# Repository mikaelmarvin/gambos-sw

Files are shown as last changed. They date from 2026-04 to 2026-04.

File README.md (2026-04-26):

# gambos

Monorepo for the Gambos project: **hardware** (schematics, PCBs, mechanical) and **software** (STM32 firmware).

| Directory | Contents |
|---|---|
| [`hardware/`](hardware/) | Hardware design files (add your KiCad, STEP, etc. here). |
| [`software/`](software/) | Firmware, CMake project, and [software/README.md](software/README.md) for build and dev container setup. |

Development (Docker, ST-Link, build scripts) is unchanged in spirit; commands now live under `software/project/`. See **software/README.md** for prerequisites, `./software/project/scripts/build.sh`, and the Dev Container workflow.

The dev container `workspaceFolder` is name-agnostic (`/workspace/project/${localWorkspaceFolderBasename}`), so repository renames do not require manual edits.

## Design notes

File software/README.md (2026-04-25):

# Gambos firmware

STM32 firmware for the Gambos project — built with CMake, developed in a **Dev Container** (Docker) at the **repository root** (see the top-level `README.md`).

## Prerequisites

| Requirement | Notes |
|---|---|
| **Git** | Clone this repository. |
| **Docker** + **Docker Compose** | Used by the dev container. |
| **Cursor** or **VS Code** | With the **Dev Containers** extension (`ms-vscode-remote.remote-containers`). |
| **Host OS** | **Linux** recommended for **USB** (ST-Link, serial) into the container. On macOS/Windows, builds work; USB passthrough needs extra host setup. |

## First-time setup (after clone)

1. **Open the repo in the editor** and choose **“Reopen in Container”** (or **Dev Containers: Reopen in Container**).
2. Wait for the image to build and **post-create** to finish. The container runs `.devcontainer/setup.sh`, which runs **`./software/project/scripts/build.sh devkit`** and fixes `compile_commands.json` paths for clangd.
3. **Open a new terminal** so the shell prompt (Starship) and `PATH` are correct.

If anything fails, run **“Dev Containers: Rebuild Container”** once.

## Build firmware

**Use the build script** (from the **repository root**):

```bash
./software/project/scripts/build.sh              # devkit (default)
./software/project/scripts/build.sh devkit     # same
```

From this directory (`software/`) you can instead run:

```bash
./project/scripts/build.sh
```

Artifacts: `software/project/build/devkit/gambos.elf`.

**ARM GCC** (`arm-none-eabi-gcc`) is installed in the container image.

If you configure manually (equivalent to what `build.sh` does), run from **`software/project/`**:

```bash
cd software/project
cmake --preset devkit
cmake --build build/devkit --parallel
```

### Other scripts (run from repo root)

| Script | Purpose |
|---|---|
| `./software/project/scripts/build.sh [devkit]` | Configure (if needed) + build |
| `./software/project/scripts/clean.sh [devkit]` | CMake `clean` for `build/devkit/` |
| `./software/project/scripts/pristine.sh [devkit\|all]` | Delete `build/devkit/`, or `all` to remove all of `software/project/build/` |
| `./software/project/scripts/probe.sh` | OpenOCD: ST-Link + MCU (STM32F4) |
| `./software/project/scripts/flash.sh` | OpenOCD: program `build/devkit/gambos.elf` (build first) |

## Editor / clangd (IntelliSense)

- `compile_commands.json` is generated under `software/project/build/devkit/` when you configure the devkit preset.
- CMSIS-SVD for register view in Cortex-Debug: **`software/STM32F446.svd`** (referenced from `.vscode/launch.json`).
- **`software/.clangd`** points firmware sources at the devkit compilation database.
- If clangd is stale, run `./software/project/scripts/build.sh` once, then **restart clangd** (command palette: **clangd: Restart language server**).

## ST-Link / USB (Linux host)

The compose file passes **`/dev/bus/usb`** and runs the service **`privileged: true`** so OpenOCD can use the ST-Link from inside the container.

On **Ubuntu**, add your user to **`dialout`** on the host if you use USB serial adapters (log out and back in):

```bash
sudo usermod -aG dialout $USER
```

After changing `docker-compose.yml`, recreate the stack:

```bash
docker compose down && docker compose up -d --build
```

Then **reopen the Dev Container**.

## Flash with OpenOCD (from the container)

After a successful build, from the **repo root**:

```bash
./software/project/scripts/flash.sh
```

Equivalent manual `openocd` lines (paths depend on your workspace location):

**F446 devkit:** `interface/stlink.cfg` + `target/stm32f4x.cfg` + `program …/software/project/build/devkit/gambos.elf verify reset exit`

Probe only: `./software/project/scripts/probe.sh`

## Repo layout (short)

| Path | Purpose |
|---|---|
| `software/project/CMakeLists.txt` | Top-level CMake |
| `software/project/scripts/gen-board-sources.sh` | Generates build inputs from Cube CMake (`build/<preset>/generated/*.cmake`) |
| `software/project/board/devkit/` | Board-specific CubeMX output |
| `software/project/app/devkit/` | Devkit application |
| `.devcontainer/` (repo root) | Dev Container definition and setup script |
| `software/.clangd` | clangd compilation database routing |
| `software/STM32F446.svd` | CMSIS-SVD for STM32F446 (peripherals in the debugger) |

More detail: `software/project/board/README.md`, `software/project/app/README.md`.

## What to commit so the next clone “just works”

Keep these in the repo (already tracked):

- **`.devcontainer/`** — container definition and `setup.sh`
- **`Dockerfile`**, **`docker-compose.yml`** — image and USB settings
- **`software/project/CMakePresets.json`**, **`software/project/CMakeLists.txt`**, **`software/project/scripts/`** — build system
- **`software/.clangd`**, **`software/.clang-format`** — editor / formatter for firmware

Avoid committing **`software/project/build/`** or editor caches — they belong in `.gitignore`.

## Troubleshooting

| Issue | What to try |
|---|---|
| clangd errors in `app/devkit` | `./software/project/scripts/build.sh` (or `cd software/project && cmake --preset devkit`), restart clangd. |
| `compile_commands` paths wrong in container | `docker compose` runs `setup.sh --post-start` to rewrite paths. |
| OpenOCD cannot see ST-Link | Host: `lsusb`; Linux + Docker: recreate container after compose changes; check `privileged` and `/dev/bus/usb` mount. |
| CMake cannot find preset | Prefer `./software/project/scripts/build.sh` from repo root, or run `cmake` from **`software/project/`**. |

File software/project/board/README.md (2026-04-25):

# Board support

## F446 devkit

CubeMX output lives under **`board/devkit/`**: **`Core/`** (or `Inc`/`Src`), **`Drivers/`**, **`Middlewares/`**, `.ioc`, and the **Cube-generated CMake** tree (`CMakeLists.txt`, **`cmake/`**).

### Two CMake entry points (both valid)

| Where you configure | Purpose |
|---|---|
| **`software/project/`** (this repo) | Builds firmware target **`gambos`**. `scripts/gen-board-sources.sh` reads Cube-generated files under `board/devkit/cmake/` and writes generated inputs under `build/devkit/generated/` (`toolchain.cmake`, `cubemx_paths.cmake`). Top `CMakeLists.txt` then consumes those generated files plus `app/${BOARD}/` and `custom_drivers`. |
| **`board/devkit/`** as CMake source root | STM32CubeIDE / Cube “generated project” flow: uses **`board/devkit/CMakeLists.txt`** and **`board/devkit/cmake/`** as shipped by Cube. |

Do not hand-edit Cube’s **`board/devkit/CMakeLists.txt`** or **`board/devkit/cmake/`** for the `gambos` build; they are treated as generated input.

- **startup** — optional in `board/devkit/`; otherwise `software/project/startup_stm32f446xx.s` is used.
- **Linker script** — `board/devkit/STM32F446XX_FLASH.ld` (path is parsed from Cube toolchain and emitted into `build/devkit/generated/toolchain.cmake`).

Build **gambos** from `software/project/`:

```bash
./scripts/build.sh devkit
```

Direct `cmake --preset devkit` works only after generated inputs already exist under `build/devkit/generated/`.

HAL/RTOS source list is parsed from Cube-generated `board/devkit/cmake/stm32cubemx/CMakeLists.txt`.

## Application code

Firmware app code: `app/devkit/` — see `app/README.md`.

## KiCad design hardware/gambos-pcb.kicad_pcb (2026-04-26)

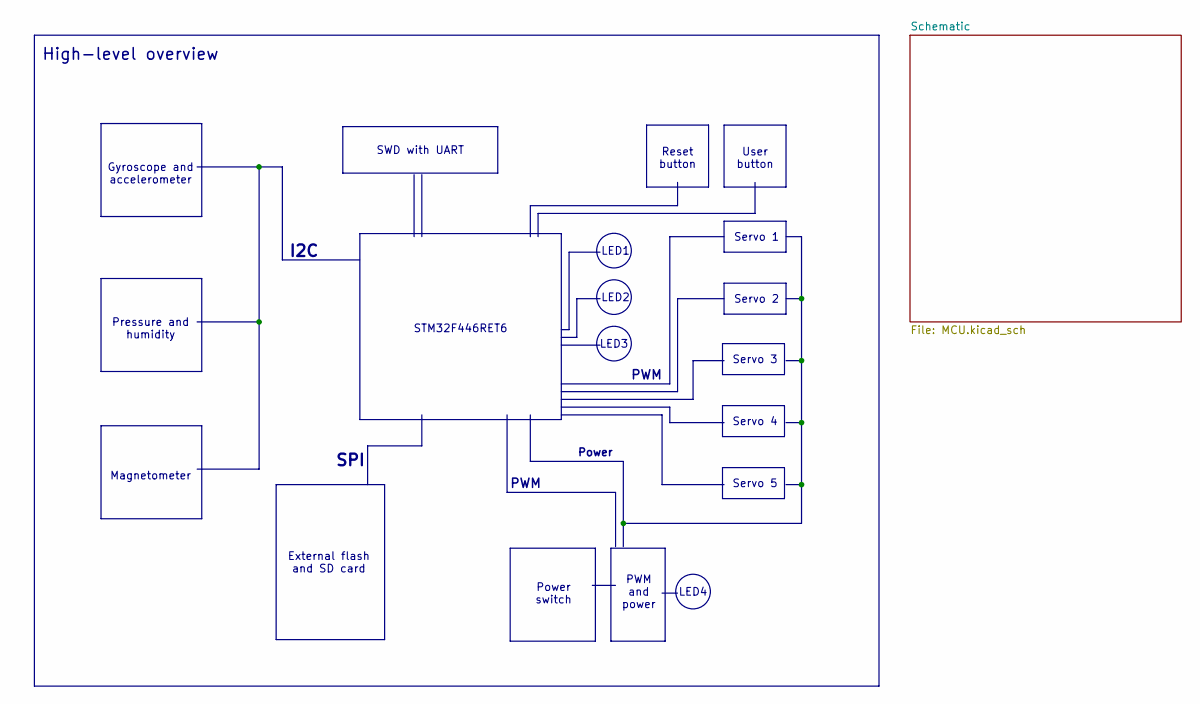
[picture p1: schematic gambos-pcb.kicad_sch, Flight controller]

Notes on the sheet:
I2C
PWM
Servo 4
Magnetometer
Servo 5
External flash and SD card
Servo 3
User button
LED1
LED4
Pressure and humidity
LED3
Power
SPI
Servo 1
High-level overview
Power switch
Reset button
LED2
Gyroscope and accelerometer
PWM and power
SWD with UART
Servo 2
STM32F446RET6

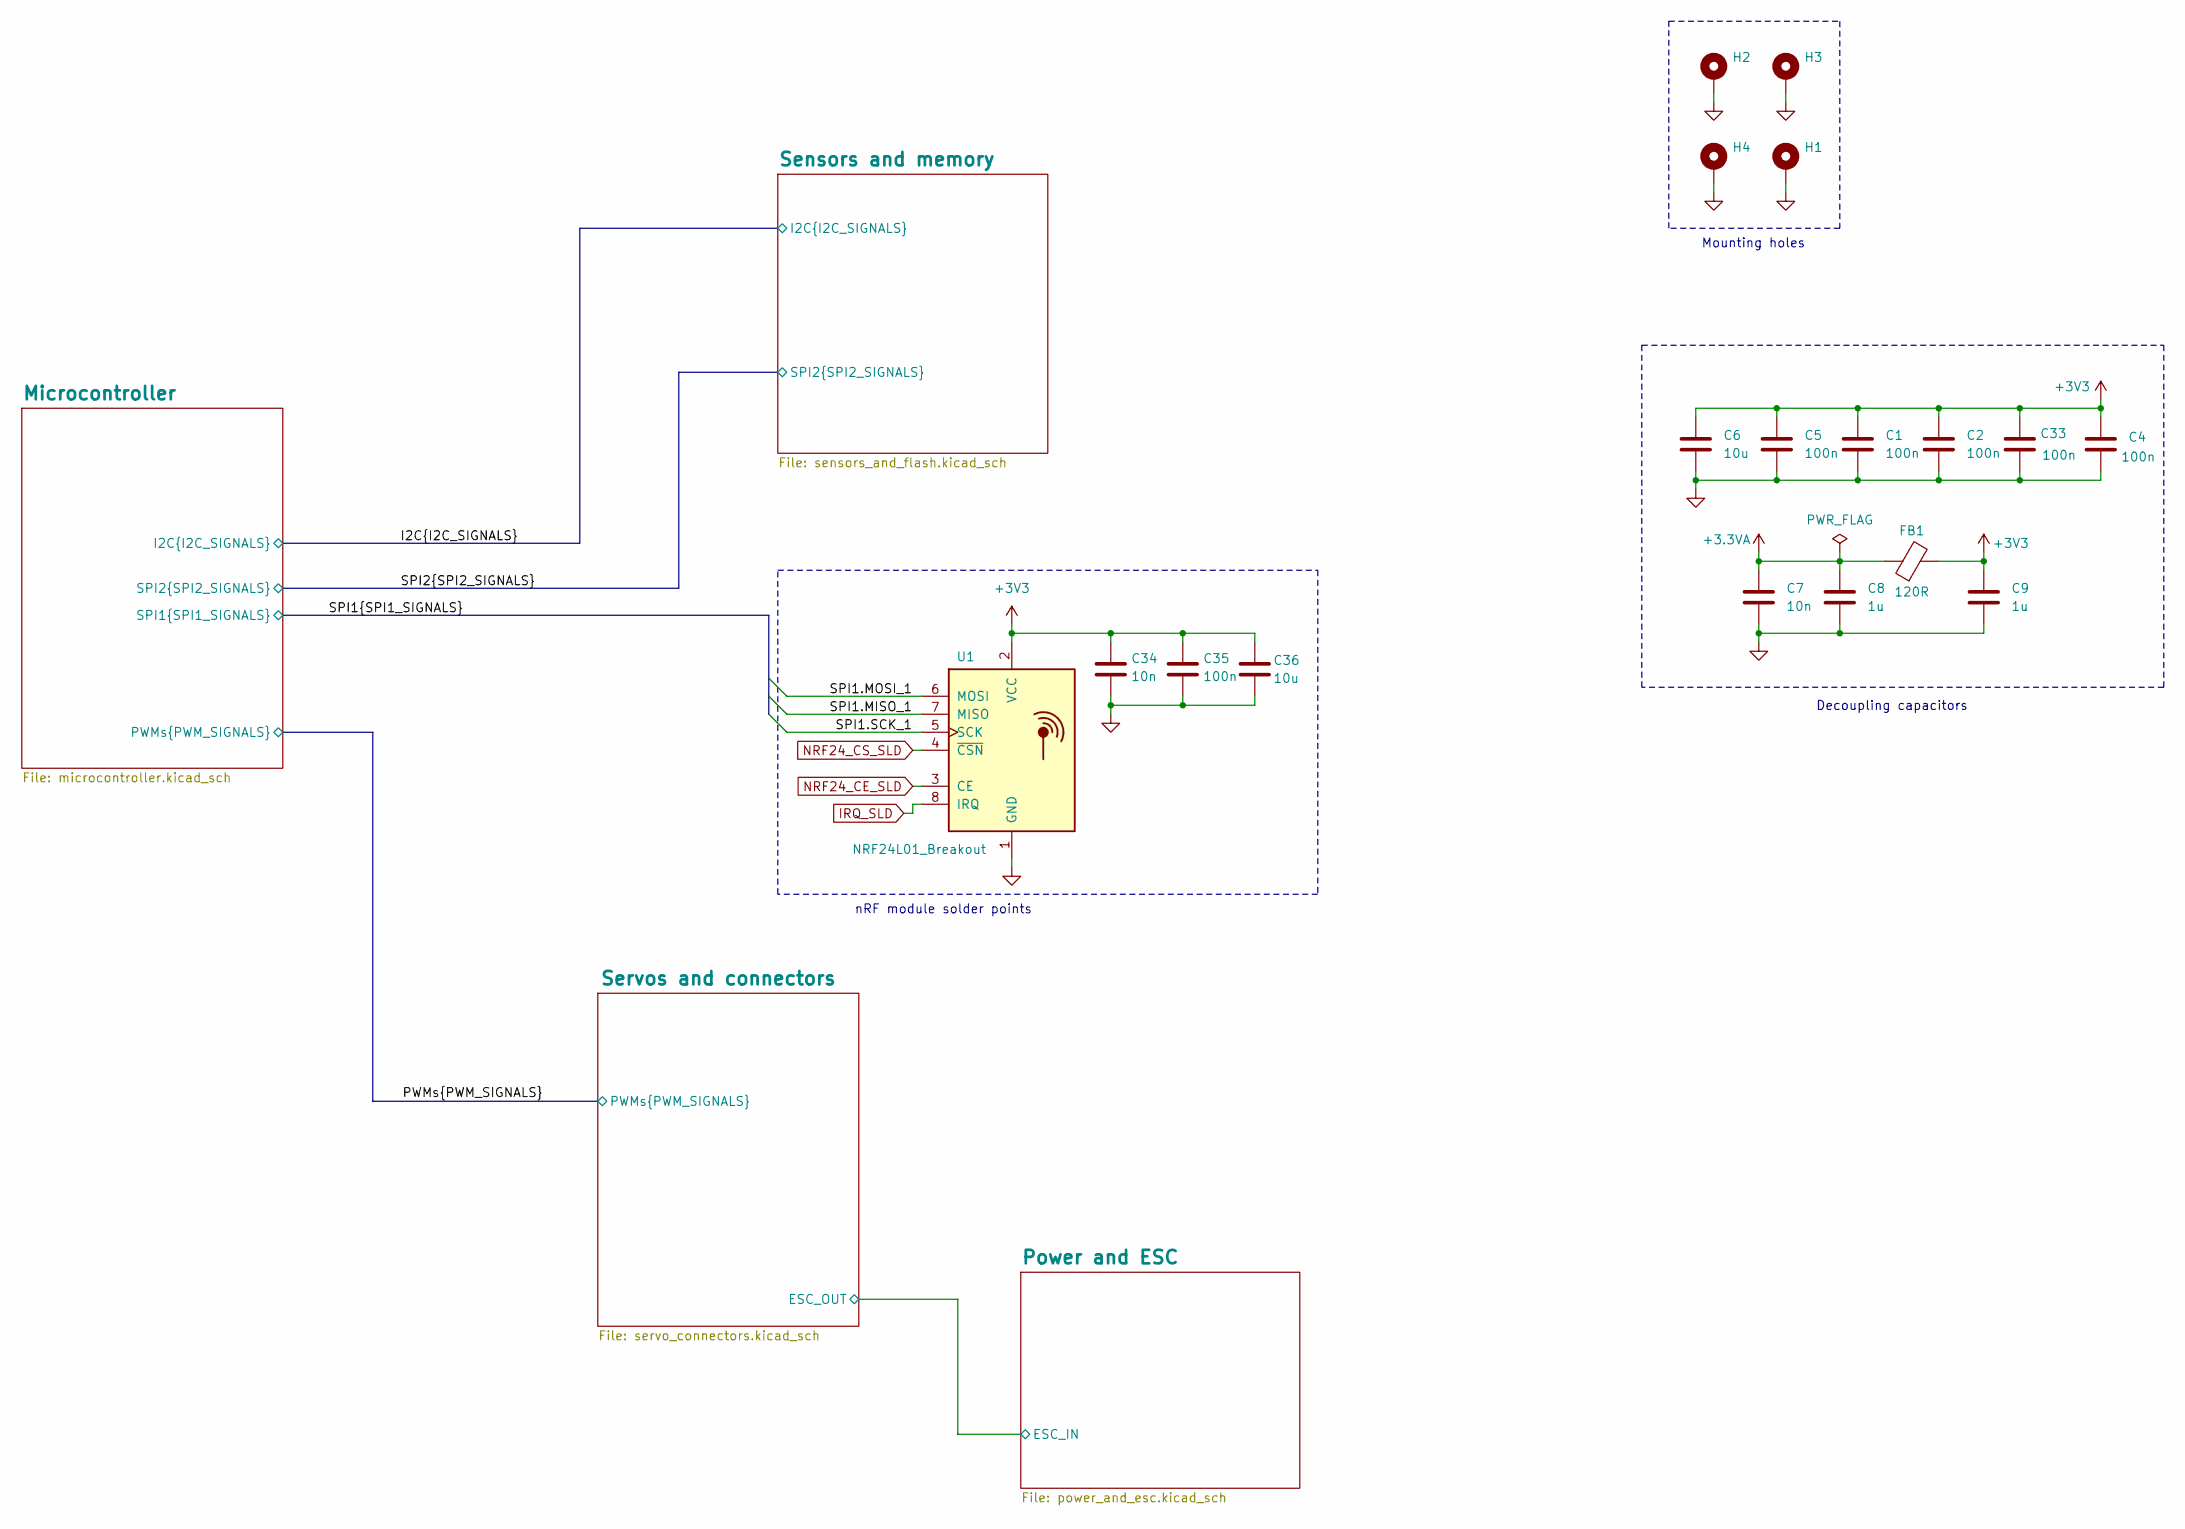
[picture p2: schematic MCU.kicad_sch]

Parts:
C1, C2, C4, C5, C33, C35: 100n; C_0603_1608Metric
C6, C36: 10u; C_0603_1608Metric
C7, C34: 10n; C_0603_1608Metric
C8, C9: 1u; C_0603_1608Metric
FB1: 120R; L_0603_1608Metric
H1, H2, H3, H4: MountingHole_Pad; MountingHole_2.2mm_M2_DIN965_Pad
U1: NRF24L01_Breakout; nRF24L01_Breakout

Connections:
+3.3VA: C7.1, C8.1, FB1.1; also elsewhere on the board
+3V3: C1.1, C2.1, C4.1, C5.1, C6.1, C9.1, C33.1, C34.1, C35.1, C36.1, FB1.2, U1.2 (VCC); also elsewhere on the board
/Schematic/SPI1.MISO_1: U1.7 (MISO); also elsewhere on the board
/Schematic/SPI1.MOSI_1: U1.6 (MOSI); also elsewhere on the board
/Schematic/SPI1.SCK_1: U1.5 (SCK); also elsewhere on the board
GND: C1.2, C2.2, C4.2, C5.2, C6.2, C7.2, C8.2, C9.2, C33.2, C34.2, C35.2, C36.2, H1.1 (1_1), H2.1 (1_1), H3.1 (1_1), H4.1 (1_1), U1.1 (GND); also elsewhere on the board
IRQ_SLD: U1.8 (IRQ); also elsewhere on the board
NRF24_CE_SLD: U1.3 (CE); also elsewhere on the board
NRF24_CS_SLD: U1.4 (~CSN); also elsewhere on the board

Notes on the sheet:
Mounting holes
nRF module solder points
Decoupling capacitors

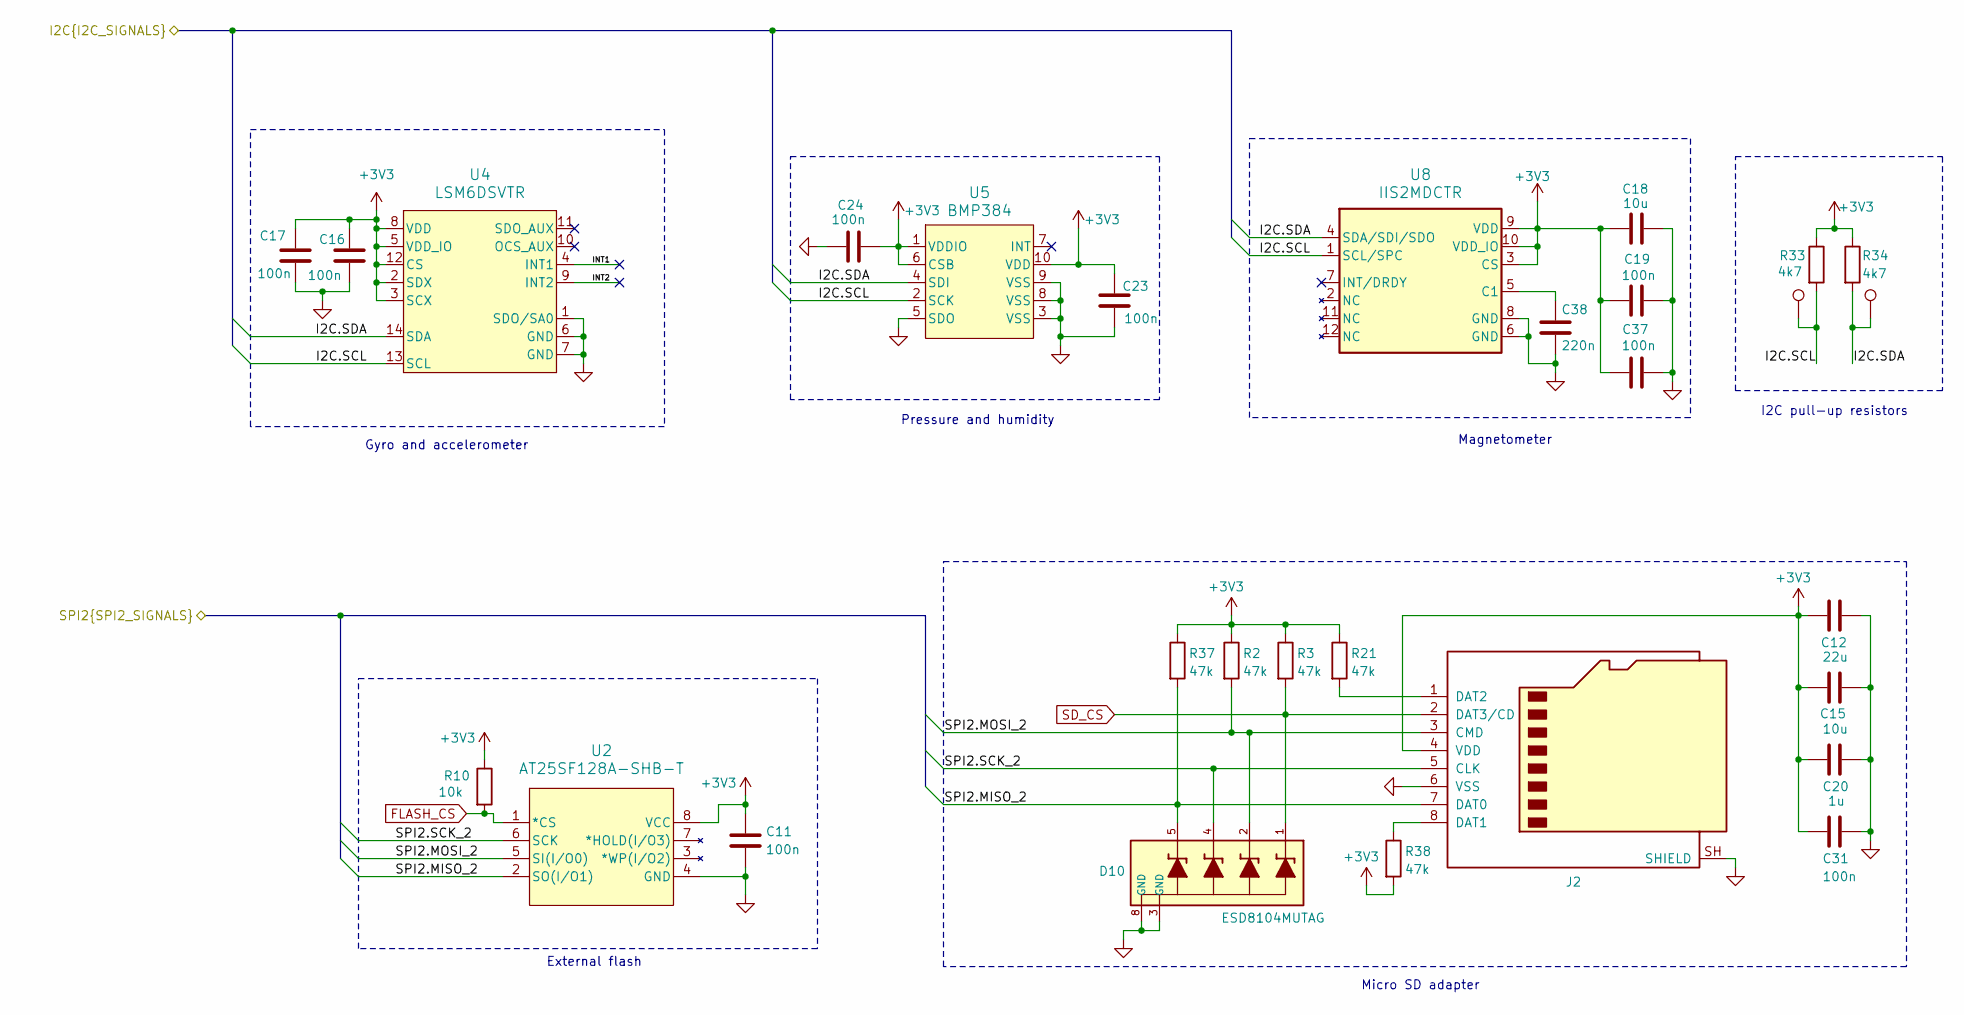
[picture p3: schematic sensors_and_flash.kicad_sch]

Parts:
C11, C16, C17, C19, C23, C24, C31, C37: 100n; C_0603_1608Metric
C12: 22u; C_0603_1608Metric
C15, C18: 10u; C_0603_1608Metric
C20: 1u; C_0603_1608Metric
C38: 220n; C_0603_1608Metric
D10: ESD8104MUTAG; DIO_ESD8104MUTAG
J2: Micro_SD_Card; GCT_MEM2067-02-180-00-A_REVB
R2, R3, R21, R37, R38: 47k; R_0603_1608Metric
R10: 10k; R_0603_1608Metric
R33, R34: 4k7; R_0603_1608Metric
TP12, TP13: TestPoint; TestPoint_Pad_D1.0mm
U2: AT25SF128A-SHB-T; IC8_AT25SF128A-SHB-T_ADO
U4: LSM6DSVTR
U5: BMP384; LGA10_2.0X2.0X0.95_BOS
U8: IIS2MDCTR; LGA-12_2X2X0P7_STM

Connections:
+3V3: C11.1, C12.2, C15.2, C16.1, C17.1, C18.1, C19.1, C20.2, C23.1, C24.2, C31.2, C37.1, J2.4 (VDD), R2.1, R3.1, R10.1, R21.1, R33.1, R34.1, R37.1, R38.2, U2.8 (VCC), U4.2 (SDX), U4.3 (SCX), U4.5 (VDD_IO), U4.8 (VDD), U4.12 (CS), U5.1 (VDDIO), U5.6 (CSB), U5.10 (VDD), U8.3 (CS), U8.9 (VDD), U8.10 (VDD_IO); also elsewhere on the board
/Schematic/I2C.SCL: R33.2, TP12.1 (1_1), U4.13 (SCL), U5.2 (SCK), U8.1 (SCL/SPC); also elsewhere on the board
/Schematic/I2C.SDA: R34.2, TP13.1 (1_1), U4.14 (SDA), U5.4 (SDI), U8.4 (SDA/SDI/SDO); also elsewhere on the board
/Schematic/SPI2.MISO_2: D10.5, J2.7 (DAT0), R37.2, U2.2 (SO(I/O1)); also elsewhere on the board
/Schematic/SPI2.MOSI_2: D10.2, J2.3 (CMD), R2.2, U2.5 (SI(I/O0)); also elsewhere on the board
/Schematic/SPI2.SCK_2: D10.4, J2.5 (CLK), U2.6 (SCK); also elsewhere on the board
/Schematic/Sensors and memory/INT1: U4.4 (INT1)
/Schematic/Sensors and memory/INT2: U4.9 (INT2)
FLASH_CS: R10.2, U2.1 (*CS); also elsewhere on the board
GND: C11.2, C12.1, C15.1, C16.2, C17.2, C18.2, C19.2, C20.1, C23.2, C24.1, C31.1, C37.2, C38.2, D10.3 (GND), D10.8 (GND), J2.6 (VSS), J2.9, J2.10, J2.11, J2.12, J2.SH (SHIELD), U2.4 (GND), U4.1 (SDO/SA0), U4.6 (GND), U4.7 (GND), U5.3 (VSS), U5.5 (SDO), U5.8 (VSS), U5.9 (VSS), U8.6 (GND), U8.8 (GND); also elsewhere on the board
unnamed: J2.8 (DAT1), R38.1
unnamed: J2.1 (DAT2), R21.2
unnamed: C38.1, U8.5 (C1)
SD_CS: D10.1, J2.2 (DAT3/CD), R3.2; also elsewhere on the board

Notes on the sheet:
External flash
Gyro and accelerometer
Pressure and humidity
Magnetometer
Micro SD adapter
I2C pull-up resistors

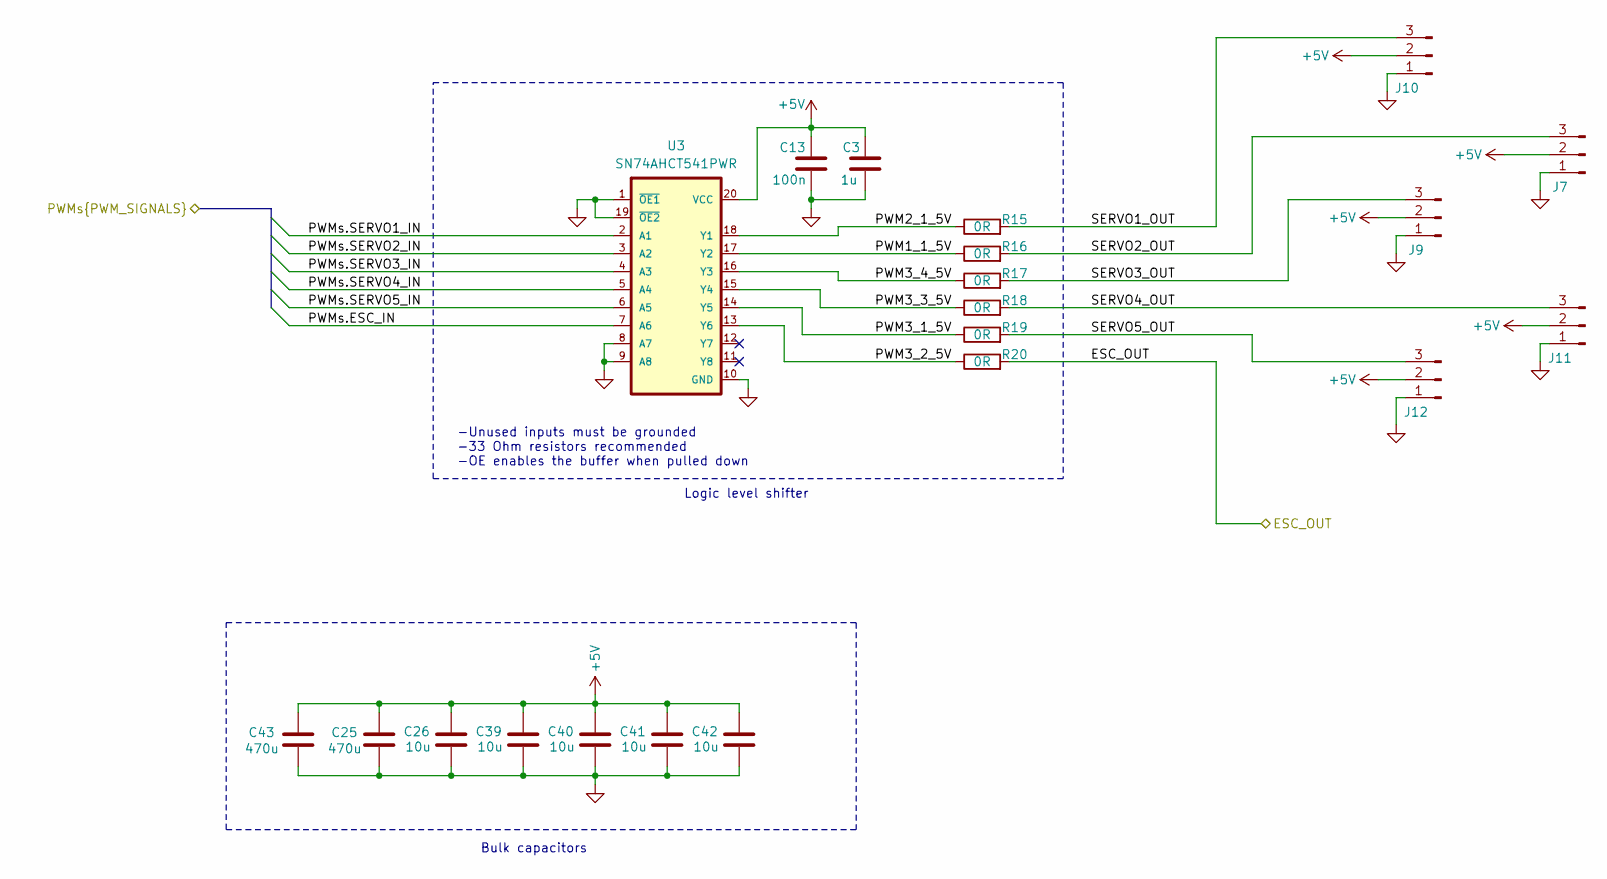
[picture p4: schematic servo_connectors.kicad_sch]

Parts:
C3: 1u; C_0603_1608Metric
C13: 100n; C_0603_1608Metric
C25, C43: 470u; WCAP-ATG8_6.3X11_DXL_
C26, C39, C40, C41, C42: 10u; C_0603_1608Metric
J7, J9, J10, J11, J12: Conn_01x03_Pin; PinHeader_1x03_P2.54mm_Vertical
R15, R16, R17, R18, R19, R20: 0R; R_0603_1608Metric
U3: SN74AHCT541PWR; SOP65P640X120-20N

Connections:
+5V: C3.1, C13.1, C25.1, C26.1, C39.1, C40.1, C41.1, C42.1, C43.1, J7.2, J9.2, J10.2, J11.2, J12.2, U3.20 (VCC); also elsewhere on the board
/Schematic/Microcontroller/PWMs.ESC_IN: U3.7 (A6); also elsewhere on the board
/Schematic/Microcontroller/PWMs.SERVO1_IN: U3.2 (A1); also elsewhere on the board
/Schematic/Microcontroller/PWMs.SERVO2_IN: U3.3 (A2); also elsewhere on the board
/Schematic/Microcontroller/PWMs.SERVO3_IN: U3.4 (A3); also elsewhere on the board
/Schematic/Microcontroller/PWMs.SERVO4_IN: U3.5 (A4); also elsewhere on the board
/Schematic/Microcontroller/PWMs.SERVO5_IN: U3.6 (A5); also elsewhere on the board
/Schematic/Servos and connectors/ESC_OUT: R20.2; also elsewhere on the board
/Schematic/Servos and connectors/PWM1_1_5V: R16.1, U3.17 (Y2)
/Schematic/Servos and connectors/PWM2_1_5V: R15.1, U3.18 (Y1)
/Schematic/Servos and connectors/PWM3_1_5V: R19.1, U3.14 (Y5)
/Schematic/Servos and connectors/PWM3_2_5V: R20.1, U3.13 (Y6)
/Schematic/Servos and connectors/PWM3_3_5V: R18.1, U3.15 (Y4)
/Schematic/Servos and connectors/PWM3_4_5V: R17.1, U3.16 (Y3)
/Schematic/Servos and connectors/SERVO1_OUT: J10.3, R15.2
/Schematic/Servos and connectors/SERVO2_OUT: J7.3, R16.2
/Schematic/Servos and connectors/SERVO3_OUT: J9.3, R17.2
/Schematic/Servos and connectors/SERVO4_OUT: J11.3, R18.2
/Schematic/Servos and connectors/SERVO5_OUT: J12.3, R19.2
GND: C3.2, C13.2, C25.2, C26.2, C39.2, C40.2, C41.2, C42.2, C43.2, J7.1, J9.1, J10.1, J11.1, J12.1, U3.1 (~OE1), U3.8 (A7), U3.9 (A8), U3.10 (GND), U3.19 (~OE2); also elsewhere on the board

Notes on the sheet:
Bulk capacitors
Logic level shifter
-Unused inputs must be grounded -33 Ohm resistors recommended -OE enables the buffer when pulled down

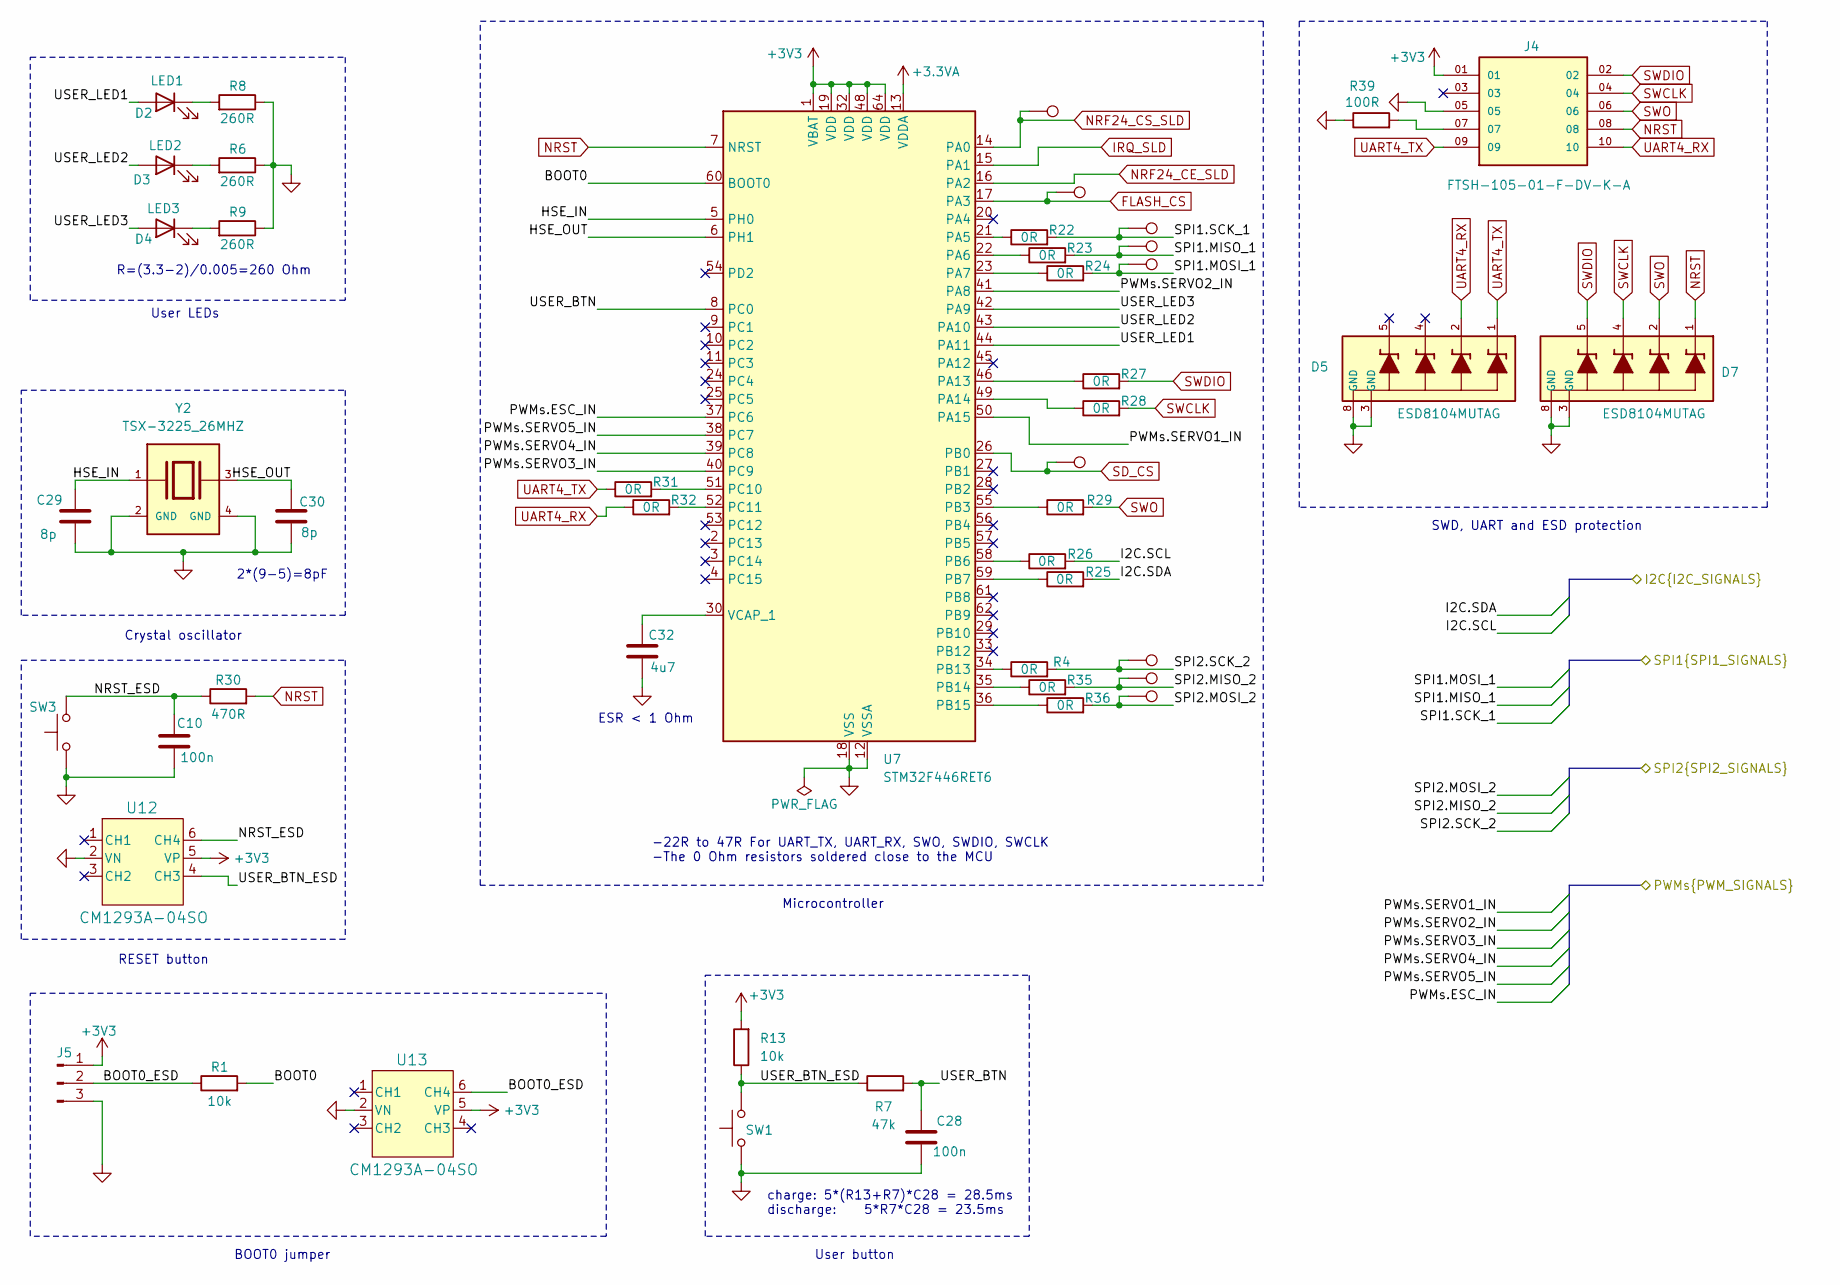
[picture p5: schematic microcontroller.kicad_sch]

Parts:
C10, C28: 100n; C_0603_1608Metric
C29, C30: 8p; C_0603_1608Metric
C32: 4u7; C_0603_1608Metric
D2: LED1; LED_0603_1608Metric
D3: LED2; LED_0603_1608Metric
D4: LED3; LED_0603_1608Metric
D5, D7: ESD8104MUTAG; DIO_ESD8104MUTAG
J4: FTSH-105-01-F-DV-K-A; SAMTEC_FTSH-105-01-F-DV-K-A
J5: Conn_01x03_Pin; PinHeader_1x03_P2.54mm_Vertical
R1, R13: 10k; R_0603_1608Metric
R4, R22, R23, R24, R25, R26, R27, R28, R29, R31, R32, R35, R36: 0R; R_0603_1608Metric
R6, R8, R9: 260R; R_0603_1608Metric
R7: 47k; R_0603_1608Metric
R30: 470R; R_0603_1608Metric
R39: 100R; R_0603_1608Metric
SW1, SW3: SW_Push; SW_Push_1P1T_NO_E-Switch_TL3301NxxxxxG
TP2, TP3, TP4, TP5, TP6, TP7, TP8, TP9, TP14: TestPoint; TestPoint_Pad_D1.0mm
U7: STM32F446RET6
U12, U13: CM1293A-04SO; SC74-6_3P1X1P7_ONS
Y2: TSX-3225_26MHZ; XTAL_TSX-3225_26.0000MF09Z-AC0

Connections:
+3.3VA: U7.13 (VDDA); also elsewhere on the board
+3V3: J4.01, J5.1, R13.2, U7.1 (VBAT), U7.19 (VDD), U7.32 (VDD), U7.48 (VDD), U7.64 (VDD), U12.5 (VP), U13.5 (VP); also elsewhere on the board
/Schematic/I2C.SCL: R26.2; also elsewhere on the board
/Schematic/I2C.SDA: R25.2; also elsewhere on the board
/Schematic/Microcontroller/BOOT0: R1.2, U7.60 (BOOT0)
/Schematic/Microcontroller/BOOT0_ESD: J5.2, R1.1, U13.6 (CH4)
/Schematic/Microcontroller/HSE_IN: C29.2, U7.5 (PH0), Y2.1
/Schematic/Microcontroller/HSE_OUT: C30.1, U7.6 (PH1), Y2.3
/Schematic/Microcontroller/NRST_ESD: C10.1, R30.1, SW3.2, U12.6 (CH4)
/Schematic/Microcontroller/PWMs.ESC_IN: U7.37 (PC6); also elsewhere on the board
/Schematic/Microcontroller/PWMs.SERVO1_IN: U7.50 (PA15); also elsewhere on the board
/Schematic/Microcontroller/PWMs.SERVO2_IN: U7.41 (PA8); also elsewhere on the board
/Schematic/Microcontroller/PWMs.SERVO3_IN: U7.40 (PC9); also elsewhere on the board
/Schematic/Microcontroller/PWMs.SERVO4_IN: U7.39 (PC8); also elsewhere on the board
/Schematic/Microcontroller/PWMs.SERVO5_IN: U7.38 (PC7); also elsewhere on the board
/Schematic/Microcontroller/USER_BTN: C28.1, R7.2, U7.8 (PC0)
/Schematic/Microcontroller/USER_BTN_ESD: R7.1, R13.1, SW1.2, U12.4 (CH3)
/Schematic/Microcontroller/USER_LED1: D2.2 (A), U7.44 (PA11)
/Schematic/Microcontroller/USER_LED2: D3.2 (A), U7.43 (PA10)
/Schematic/Microcontroller/USER_LED3: D4.2 (A), U7.42 (PA9)
/Schematic/SPI1.MISO_1: R23.2, TP4.1 (1_1); also elsewhere on the board
/Schematic/SPI1.MOSI_1: R24.2, TP5.1 (1_1); also elsewhere on the board
/Schematic/SPI1.SCK_1: R22.2, TP3.1 (1_1); also elsewhere on the board
/Schematic/SPI2.MISO_2: R35.2, TP7.1 (1_1); also elsewhere on the board
/Schematic/SPI2.MOSI_2: R36.2, TP14.1 (1_1); also elsewhere on the board
/Schematic/SPI2.SCK_2: R4.2, TP6.1 (1_1); also elsewhere on the board
FLASH_CS: TP9.1 (1_1), U7.17 (PA3); also elsewhere on the board
GND: C10.2, C28.2, C29.1, C30.2, C32.2, D5.3 (GND), D5.8 (GND), D7.3 (GND), D7.8 (GND), J4.05, J5.3, R6.1, R8.1, R9.1, R39.1, SW1.1, SW3.1, U7.12 (VSSA), U7.18 (VSS), U7.31 (VSS), U7.47 (VSS), U7.63 (VSS), U12.2 (VN), U13.2 (VN), Y2.2 (GND), Y2.4 (GND); also elsewhere on the board
IRQ_SLD: U7.15 (PA1); also elsewhere on the board
NRF24_CE_SLD: U7.16 (PA2); also elsewhere on the board
NRF24_CS_SLD: TP2.1 (1_1), U7.14 (PA0); also elsewhere on the board
NRST: D7.1, J4.08, R30.2, U7.7 (NRST)
unnamed: D2.1 (K), R8.2
unnamed: D3.1 (K), R6.2
unnamed: D4.1 (K), R9.2
unnamed: J4.07, R39.2
unnamed: R22.1, U7.21 (PA5)
unnamed: R23.1, U7.22 (PA6)
unnamed: R24.1, U7.23 (PA7)
unnamed: R27.1, U7.46 (PA13)
unnamed: R28.1, U7.49 (PA14)
unnamed: R29.1, U7.55 (PB3)
unnamed: R26.1, U7.58 (PB6)
unnamed: R25.1, U7.59 (PB7)
unnamed: R4.1, U7.34 (PB13)
unnamed: R35.1, U7.35 (PB14)
unnamed: R36.1, U7.36 (PB15)
unnamed: R31.2, U7.51 (PC10)
unnamed: R32.2, U7.52 (PC11)
unnamed: C32.1, U7.30 (VCAP_1)
SD_CS: TP8.1 (1_1), U7.26 (PB0); also elsewhere on the board
SWCLK: D7.4, J4.04, R28.2
SWDIO: D7.5, J4.02, R27.2
SWO: D7.2, J4.06, R29.2
UART4_RX: D5.2, J4.10, R32.1
UART4_TX: D5.1, J4.09, R31.1

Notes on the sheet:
2*(9-5)=8pF
-22R to 47R For UART_TX, UART_RX, SWO, SWDIO, SWCLK -The 0 Ohm resistors soldered close to the MCU
R=(3.3-2)/0.005=260 Ohm
User LEDs
charge: 5*(R13+R7)*C28 = 28.5ms discharge: 5*R7*C28 = 23.5ms
ESR < 1 Ohm
SWD, UART and ESD protection
Crystal oscillator
BOOT0 jumper
User button
RESET button
Microcontroller

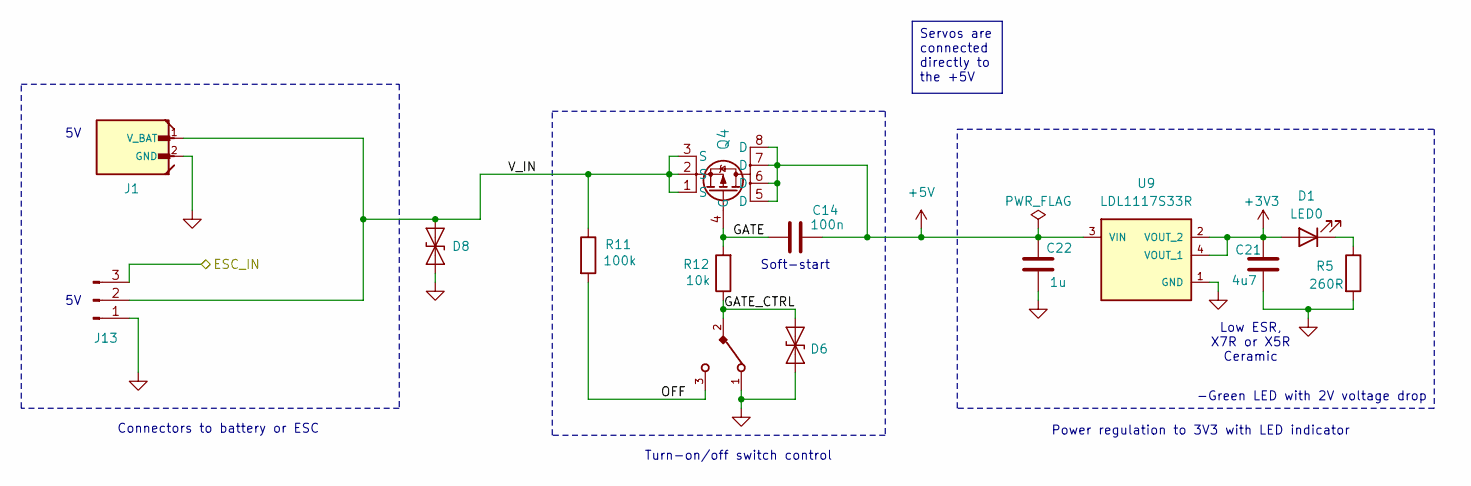
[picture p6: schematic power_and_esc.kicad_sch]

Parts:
C14: 100n; C_0603_1608Metric
C21: 4u7; C_0603_1608Metric
C22: 1u; C_0603_1608Metric
D1: LED0; LED_0603_1608Metric
D6, D8: SMAJ5.0CA; D_SMA
J1: JST-PH
J13: Conn_01x03_Pin; PinHeader_1x03_P2.54mm_Vertical
Q4: DMP3010LPSQ-13
R5: 260R; R_0603_1608Metric
R11: 100k; R_0603_1608Metric
R12: 10k; R_0603_1608Metric
Slide_SW1: 450404015514
U9: LDL1117S33R

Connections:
+3V3: C21.1, D1.2 (A), U9.2 (VOUT_2), U9.4 (VOUT_1); also elsewhere on the board
+5V: C14.1, C22.1, Q4.5 (D), Q4.6 (D), Q4.7 (D), Q4.8 (D), U9.3 (VIN); also elsewhere on the board
/Schematic/Power and ESC/GATE: C14.2, Q4.4 (G), R12.2
/Schematic/Power and ESC/GATE_CTRL: D6.2 (A2), R12.1, Slide_SW1.2
/Schematic/Power and ESC/OFF: R11.2, Slide_SW1.3
/Schematic/Power and ESC/V_IN: D8.2 (A2), J1.1 (V_BAT), J13.2, Q4.1 (S), Q4.2 (S), Q4.3 (S), R11.1
/Schematic/Servos and connectors/ESC_OUT: J13.3; also elsewhere on the board
GND: C21.2, C22.2, D6.1 (A1), D8.1 (A1), J1.2 (GND), J13.1, R5.2, Slide_SW1.1, Slide_SW1.Z1, Slide_SW1.Z2, Slide_SW1.Z3, Slide_SW1.Z4, U9.1 (GND); also elsewhere on the board
unnamed: D1.1 (K), R5.1

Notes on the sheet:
Low ESR, X7R or X5R Ceramic
Connectors to battery or ESC
Power regulation to 3V3 with LED indicator
Turn-on/off switch control
Soft-start
-Green LED with 2V voltage drop
Servos are connected directly to the +5V

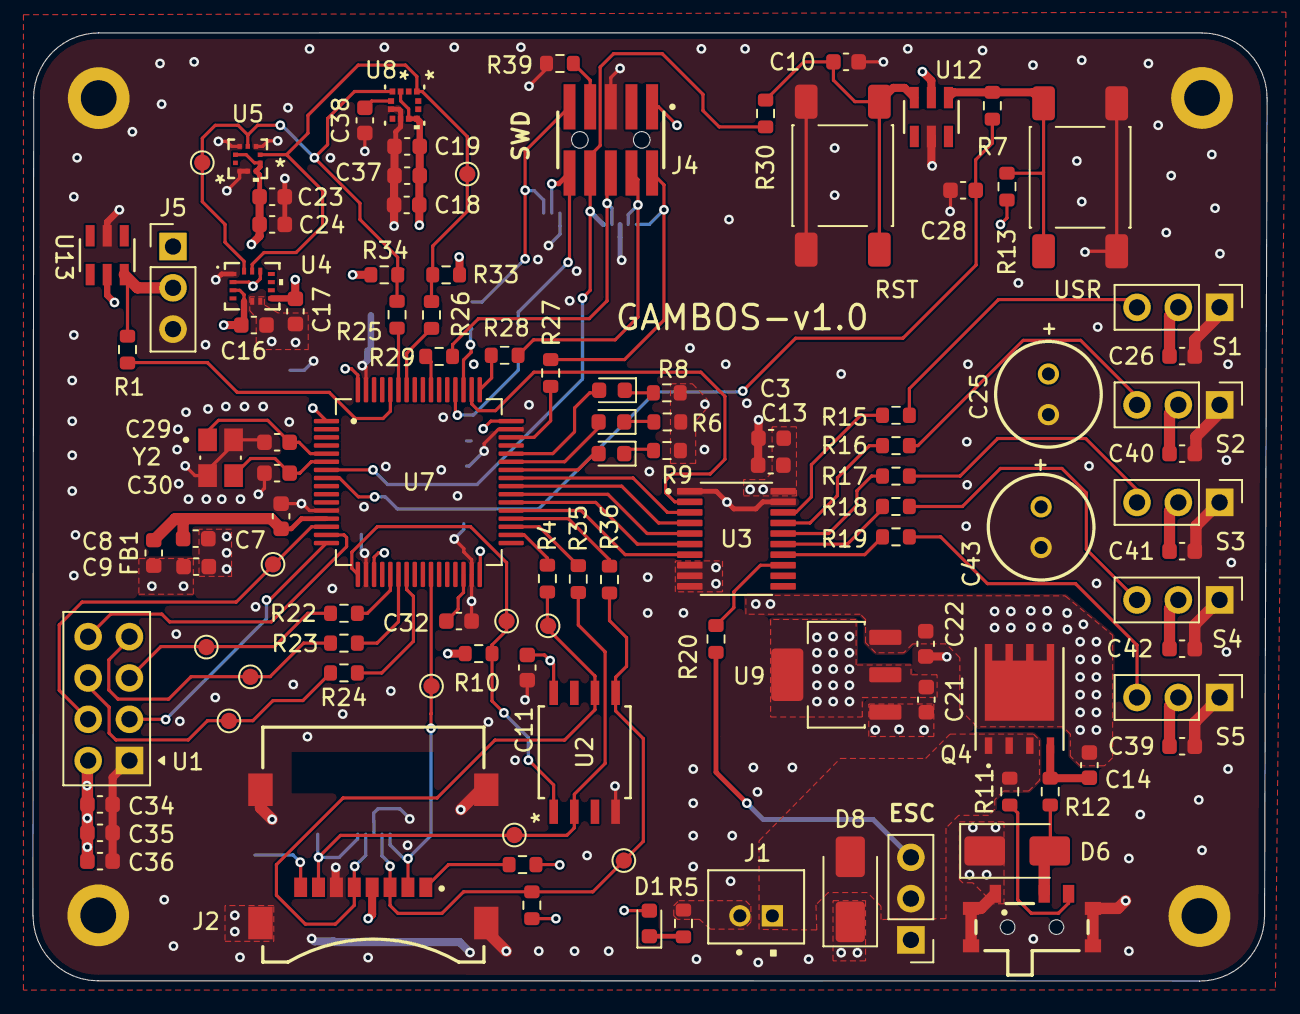
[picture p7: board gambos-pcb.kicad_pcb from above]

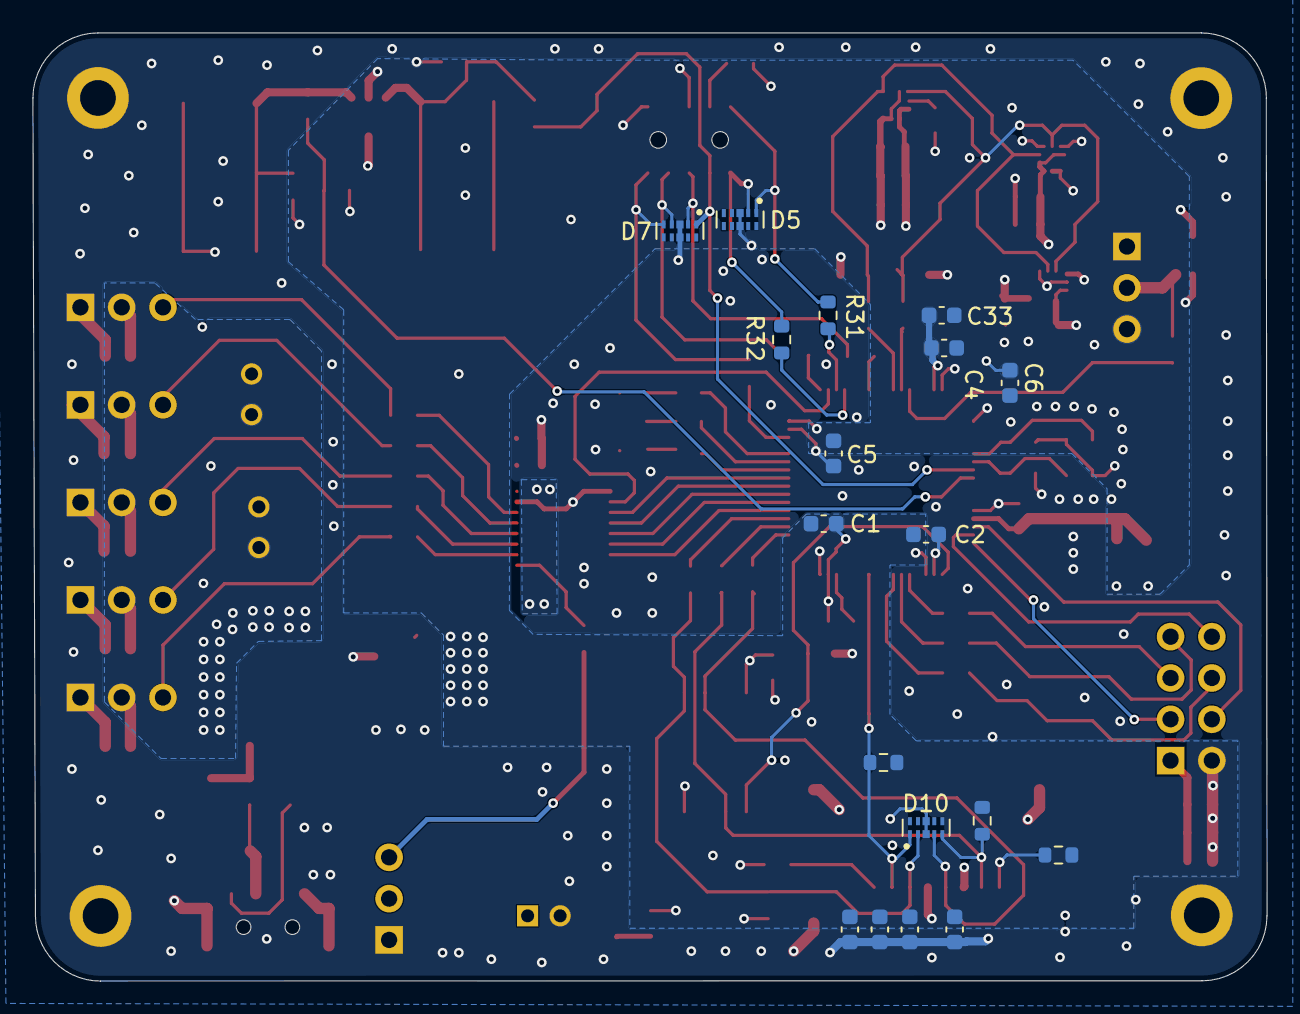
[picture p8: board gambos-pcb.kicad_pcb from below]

Board: 4 copper layers, 75.9 x 58.3 mm, 130 parts (18 on the bottom side), 77 nets.

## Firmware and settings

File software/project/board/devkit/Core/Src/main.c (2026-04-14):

#include "main.h"
#include "cmsis_os.h"
#include "dma.h"
#include "gpio.h"
#include "spi.h"
#include "usart.h"

#include "app/app.hpp"

void SystemClock_Config(void);
void MX_FREERTOS_Init(void);

/**
 * @brief  The application entry point.
 * @retval int
 */
int main(void) {
    HAL_Init();

    SystemClock_Config();

    MX_GPIO_Init();
    MX_DMA_Init();
    MX_SPI2_Init();
    MX_USART2_UART_Init();
    app_init();
    osKernelInitialize();
    MX_FREERTOS_Init();
    osKernelStart();

    while (1) {}
}

/**
 * @brief System Clock Configuration
 * @retval None
 */
void SystemClock_Config(void) {
    RCC_OscInitTypeDef RCC_OscInitStruct = {0};
    RCC_ClkInitTypeDef RCC_ClkInitStruct = {0};

    /** Configure the main internal regulator output voltage
     */
    __HAL_RCC_PWR_CLK_ENABLE();
    __HAL_PWR_VOLTAGESCALING_CONFIG(PWR_REGULATOR_VOLTAGE_SCALE3);

    /** Initializes the RCC Oscillators according to the specified
     * parameters in the RCC_OscInitTypeDef structure.
     */
    RCC_OscInitStruct.OscillatorType = RCC_OSCILLATORTYPE_HSI;
    RCC_OscInitStruct.HSIState = RCC_HSI_ON;
    RCC_OscInitStruct.HSICalibrationValue =
        RCC_HSICALIBRATION_DEFAULT;
    RCC_OscInitStruct.PLL.PLLState = RCC_PLL_ON;
    RCC_OscInitStruct.PLL.PLLSource = RCC_PLLSOURCE_HSI;
    RCC_OscInitStruct.PLL.PLLM = 16;
    RCC_OscInitStruct.PLL.PLLN = 336;
    RCC_OscInitStruct.PLL.PLLP = RCC_PLLP_DIV4;
    RCC_OscInitStruct.PLL.PLLQ = 2;
    RCC_OscInitStruct.PLL.PLLR = 2;
    if (HAL_RCC_OscConfig(&RCC_OscInitStruct) != HAL_OK) {
        Error_Handler();
    }

    /** Initializes the CPU, AHB and APB buses clocks
     */
    RCC_ClkInitStruct.ClockType =
        RCC_CLOCKTYPE_HCLK | RCC_CLOCKTYPE_SYSCLK |
        RCC_CLOCKTYPE_PCLK1 | RCC_CLOCKTYPE_PCLK2;
    RCC_ClkInitStruct.SYSCLKSource = RCC_SYSCLKSOURCE_PLLCLK;
    RCC_ClkInitStruct.AHBCLKDivider = RCC_SYSCLK_DIV1;
    RCC_ClkInitStruct.APB1CLKDivider = RCC_HCLK_DIV2;
    RCC_ClkInitStruct.APB2CLKDivider = RCC_HCLK_DIV1;

    if (HAL_RCC_ClockConfig(&RCC_ClkInitStruct, FLASH_LATENCY_2) !=
        HAL_OK) {
        Error_Handler();
    }
}

/**
 * @brief  Period elapsed callback in non blocking mode
 * @note   This function is called  when TIM1 interrupt took place,
 * inside HAL_TIM_IRQHandler(). It makes a direct call to
 * HAL_IncTick() to increment a global variable "uwTick" used as
 * application time base.
 * @param  htim : TIM handle
 * @retval None
 */
void HAL_TIM_PeriodElapsedCallback(TIM_HandleTypeDef *htim) {
    if (htim->Instance == TIM1) {
        HAL_IncTick();
    }
}

/**
 * @brief  This function is executed in case of error occurrence.
 * @retval None
 */
void Error_Handler(void) {
    __disable_irq();
    while (1) {}
}
#ifdef USE_FULL_ASSERT
/**
 * @brief  Reports the name of the source file and the source line
 * number where the assert_param error has occurred.
 * @param  file: pointer to the source file name
 * @param  line: assert_param error line source number
 * @retval None
 */
void assert_failed(uint8_t *file, uint32_t line) {
    (void)file;
    (void)line;
    /* User can add his own implementation to report the file name and
       line number, ex: printf("Wrong parameters value: file %s on
       line %d\r\n", file, line) */
}
#endif /* USE_FULL_ASSERT */

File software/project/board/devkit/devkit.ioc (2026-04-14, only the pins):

Mcu.UserName=STM32F446RETx
PA13.GPIO_Label=TMS
PA13.Signal=SYS_JTMS-SWDIO
PA14.GPIO_Label=TCK
PA14.Signal=SYS_JTCK-SWCLK
PA2.GPIO_Label=USART_TX
PA2.Signal=USART2_TX
PA3.GPIO_Label=USART_RX
PA3.Signal=USART2_RX
PA5.GPIO_Label=LD2 [Green Led]
PA5.Signal=GPIO_Output
PB10.Signal=SPI2_SCK
PB3.GPIO_Label=SWO
PB3.Signal=SYS_JTDO-SWO
PC1.Signal=SPI2_MOSI
PC13.GPIO_Label=B1 [Blue PushButton]
PC13.Signal=GPXTI13
PC14-OSC32_IN.Signal=RCC_OSC32_IN
PC15-OSC32_OUT.Signal=RCC_OSC32_OUT
PC2.Signal=SPI2_MISO
PC7.GPIO_Label=CS2
PC7.Signal=GPIO_Output
PC9.GPIO_Label=CS1
PC9.Signal=GPIO_Output
PH0-OSC_IN.Signal=RCC_OSC_IN
PH1-OSC_OUT.Signal=RCC_OSC_OUT

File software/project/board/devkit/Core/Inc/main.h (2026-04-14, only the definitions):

#define B1_Pin GPIO_PIN_13
#define B1_GPIO_Port GPIOC
#define B1_EXTI_IRQn EXTI15_10_IRQn
#define USART_TX_Pin GPIO_PIN_2
#define USART_TX_GPIO_Port GPIOA
#define USART_RX_Pin GPIO_PIN_3
#define USART_RX_GPIO_Port GPIOA
#define LD2_Pin GPIO_PIN_5
#define LD2_GPIO_Port GPIOA
#define CS2_Pin GPIO_PIN_7
#define CS2_GPIO_Port GPIOC
#define CS1_Pin GPIO_PIN_9
#define CS1_GPIO_Port GPIOC
#define TMS_Pin GPIO_PIN_13
#define TMS_GPIO_Port GPIOA
#define TCK_Pin GPIO_PIN_14
#define TCK_GPIO_Port GPIOA
#define SWO_Pin GPIO_PIN_3
#define SWO_GPIO_Port GPIOB

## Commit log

2026-02-28 Removed some more unnecessary comments from i2c.c and deleted the unnecessary Release build preset
2026-03-03 Added initialization code for devkit and custom pcb to the project, now it is possible to build both
2026-04-13 Flashed something useful, messaging, button handler and tested subscribing
2026-04-13 flashed, tried messaging, button handler ...
2026-04-24 fix: restructured repo for hardware integration
    [app.cpp, button_handler.cpp, devkit.ioc]
2026-04-26 Added new hardware files
    [MCU.kicad_sch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]

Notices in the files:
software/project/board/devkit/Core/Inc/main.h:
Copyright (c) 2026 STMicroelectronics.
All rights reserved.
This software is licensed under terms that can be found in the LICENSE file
